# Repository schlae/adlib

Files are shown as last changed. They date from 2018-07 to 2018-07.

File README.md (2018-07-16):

# adlib
Reproduction AdLib Sound Card, OPL2, Circa 1990

For details see http://tubetime.us/?p=419.

This is a (nearly) exact clone of the 1990 version of the AdLib sound card.

User root42 has created a Mouser project with the parts in the BOM at https://www.mouser.com/ProjectManager/ProjectDetail.aspx?AccessID=b0869fd937

This work is licensed under a Creative Commons Attribution 4.0 International License. See https://creativecommons.org/licenses/by/4.0/

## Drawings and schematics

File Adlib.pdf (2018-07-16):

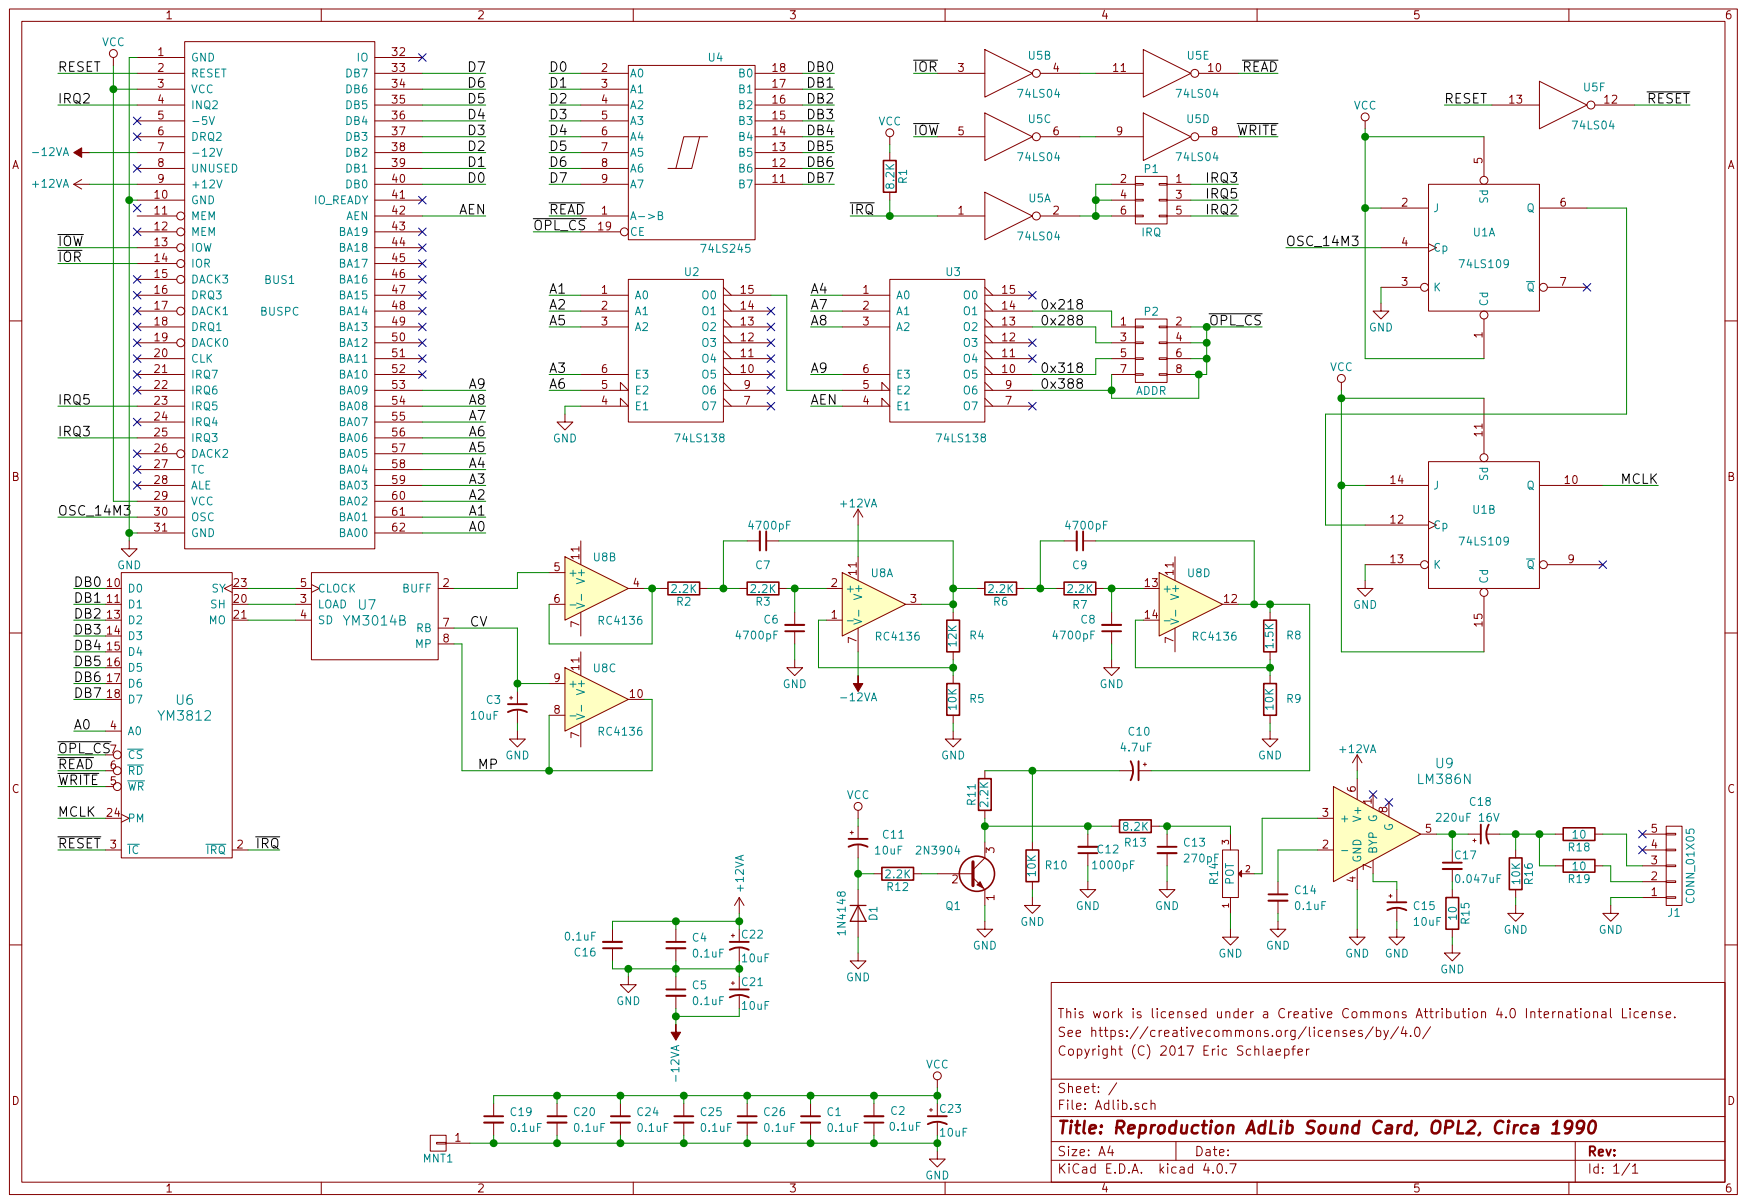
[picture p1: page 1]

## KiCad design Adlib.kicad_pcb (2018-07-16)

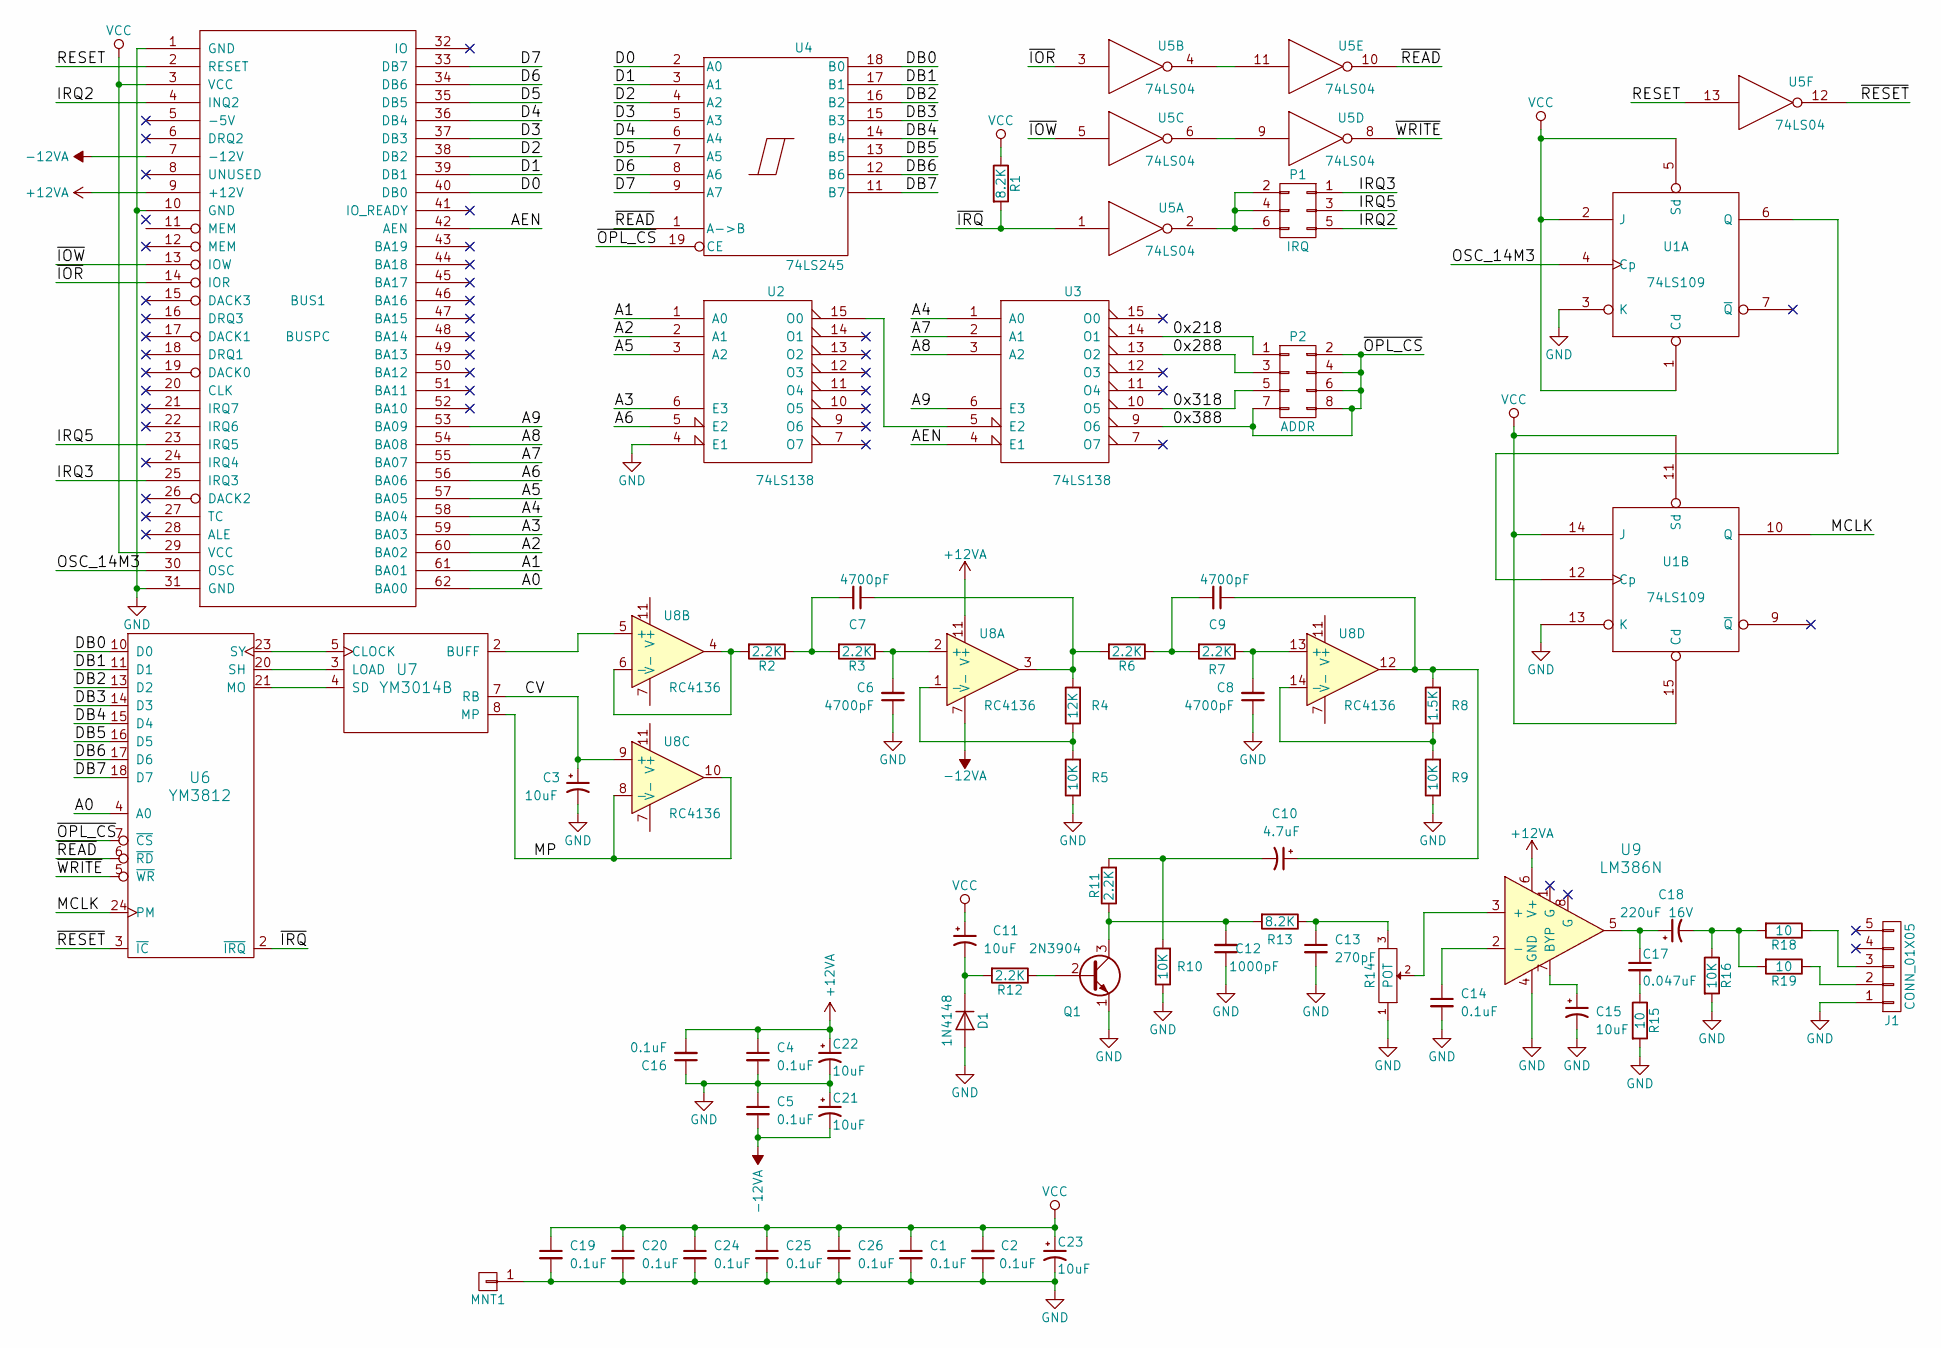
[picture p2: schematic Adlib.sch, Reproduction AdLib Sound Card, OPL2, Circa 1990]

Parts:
BUS1: BUSPC; BUS_PC_ADLIB
C1, C2, C4, C5, C14, C16, C19, C20, C24, C25, C26: 0.1uF; CAP23; Mouser 581-AR215C104K4R
C3, C11, C15, C21, C22, C23: 10uF; CAPAP200; Mouser 581-TAP106M025CRW
C6, C7, C8, C9: 4700pF; CAP23; Mouser 581-AR211C472K4R
C10: 4.7uF; CAPAP200; Mouser 581-TAP475K016SCS
C12: 1000pF; CAP23; Mouser 581-AR211C102K4R
C13: 270pF; CAP23; Mouser 594-S271K43SL0N6TK5R
C17: 0.047uF; CAP23; Mouser 581-AR215C473K4R
C18: 220uF 16V; CAPA1000; Mouser 647-TVX1C221MAD
D1: 1N4148; DIOA500; Mouser 512-1N4148
J1: CONN_01X05; JACK_CUI_SJ1-3553NG; Mouser 490-SJ1-3553NG
MNT1: CONN_01X01; MNT_KEYSTONE_9202; Mouser 534-9202
P1: IRQ; JMP3
P2: ADDR; JMP4
Q1: 2N3904; TO92-IL; Mouser 512-2N3904BU
R1, R13: 8.2K; RESA500; Mouser 291-8.2K-RC
R2, R3, R6, R7, R11, R12: 2.2K; RESA500; Mouser 291-2.2K-RC
R4: 12K; RESA500; Mouser 291-12K-RC
R5, R9, R10, R16: 10K; RESA500; Mouser 291-10K-RC
R8: 1.5K; RESA500; Mouser 291-1.5K-RC
R14: POT; RESV_BOURNS_91A1A; Mouser 652-91A1A-B24-D15L
R15, R18, R19: 10; RESA500; Mouser 291-10-RC
U1: 74LS109; DIP300_16N; Mouser 595-SN74LS109AN
U2, U3: 74LS138; DIP300_16N; Mouser 595-SN74LS138N
U4: 74LS245; DIP300_20N; Mouser 595-SN74LS245N
U5: 74LS04; DIP300_14N; Mouser 595-SN74LS04N
U6: YM3812; DIP600_24N
U7: YM3014B; DIP300_8N
U8: RC4136; DIP300_14N; Mouser 595-RC4136N
U9: LM386N; DIP300_8N; Mouser 926-LM386N-4/NOPB

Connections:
+12VA: BUS1.9 (+12V), C4.1, C16.2, C22.1, U8.11 (V+), U9.6 (V+)
-12VA: BUS1.7 (-12V), C5.2, C21.2, U8.7 (V-)
/0x218: P2.1, U3.14 (O1)
/0x288: P2.3, U3.13 (O2)
/0x318: P2.5, U3.10 (O5)
/0x388: P2.2, P2.4, P2.6, P2.7, P2.8, U3.9 (O6), U4.19 (CE), U6.7 (~CS)
/A0: BUS1.62 (BA00), U6.4 (A0)
/A1: BUS1.61 (BA01), U2.1 (A0)
/A2: BUS1.60 (BA02), U2.2 (A1)
/A3: BUS1.59 (BA03), U2.6 (E3)
/A4: BUS1.58 (BA04), U3.1 (A0)
/A5: BUS1.57 (BA05), U2.3 (A2)
/A6: BUS1.56 (BA06), U2.5 (E2)
/A7: BUS1.55 (BA07), U3.2 (A1)
/A8: BUS1.54 (BA08), U3.3 (A2)
/A9: BUS1.53 (BA09), U3.6 (E3)
/AEN: BUS1.42 (AEN), U3.4 (E1)
/CV: C3.1, U7.7 (RB), U8.9 (+)
/D0: BUS1.40 (DB0), U4.2 (A0)
/D1: BUS1.39 (DB1), U4.3 (A1)
/D2: BUS1.38 (DB2), U4.4 (A2)
/D3: BUS1.37 (DB3), U4.5 (A3)
/D4: BUS1.36 (DB4), U4.6 (A4)
/D5: BUS1.35 (DB5), U4.7 (A5)
/D6: BUS1.34 (DB6), U4.8 (A6)
/D7: BUS1.33 (DB7), U4.9 (A7)
/DB0: U4.18 (B0), U6.10 (D0)
/DB1: U4.17 (B1), U6.11 (D1)
/DB2: U4.16 (B2), U6.13 (D2)
/DB3: U4.15 (B3), U6.14 (D3)
/DB4: U4.14 (B4), U6.15 (D4)
/DB5: U4.13 (B5), U6.16 (D5)
/DB6: U4.12 (B6), U6.17 (D6)
/DB7: U4.11 (B7), U6.18 (D7)
/IRQ2: BUS1.4 (INQ2), P1.5
/IRQ3: BUS1.25 (IRQ3), P1.1
/IRQ5: BUS1.23 (IRQ5), P1.3
/MCLK: U1.10 (Q), U6.24 (PM)
/MP: U7.8 (MP), U8.8 (-), U8.10
/OSC_14M3: BUS1.30 (OSC), U1.4 (Cp)
/RESET: BUS1.2 (RESET), U5.13
/~IOR: BUS1.14 (IOR), U5.3
/~IOW: BUS1.13 (IOW), U5.5
/~IRQ: R1.2, U5.1, U6.2 (~IRQ)
/~READ: U4.1 (A->B), U5.10, U6.6 (~RD)
/~RESET: U5.12, U6.3 (~IC)
/~WRITE: U5.8, U6.5 (~WR)
GND: BUS1.1 (GND), BUS1.10 (GND), BUS1.31 (GND), C1.2, C2.1, C3.2, C4.2, C5.1, C6.1, C8.1, C12.1, C13.2, C14.2, C15.2, C16.1, C19.2, C20.2, C21.1, C22.2, C23.2, C24.2, C25.2, C26.2, D1.2 (A), J1.1, MNT1.1, Q1.1 (E), R5.1, R9.1, R10.1, R14.1, R15.2, R16.2, U1.3 (K), U1.8 (GND), U1.13 (K), U2.4 (E1), U2.8 (GND), U3.8 (GND), U4.10 (GND), U5.7 (GND), U6.12 (GND), U7.6 (GND), U9.4 (GND)
unnamed: C6.2, R3.1, U8.2 (+)
unnamed: C7.1, R4.2, R6.2, U8.3
unnamed: C7.2, R2.1, R3.2
unnamed: C8.2, R7.1, U8.13 (+)
unnamed: C9.2, R6.1, R7.2
unnamed: C9.1, C10.1, R8.2, U8.12
unnamed: C10.2, R10.2, R11.2
unnamed: C11.2, D1.1 (K), R12.2
unnamed: C12.2, Q1.3 (C), R11.1, R13.2
unnamed: C13.1, R13.1, R14.3
unnamed: C14.1, U9.2 (-)
unnamed: C15.1, U9.7 (BYP)
unnamed: C17.1, C18.1, U9.5
unnamed: C17.2, R15.1
unnamed: C18.2, R16.1, R18.2, R19.2
unnamed: J1.2, R19.1
unnamed: J1.3, R18.1
unnamed: P1.2, P1.4, P1.6, U5.2
unnamed: Q1.2 (B), R12.1
unnamed: R2.2, U8.4, U8.6 (-)
unnamed: R4.1, R5.2, U8.1 (-)
unnamed: R8.1, R9.2, U8.14 (-)
unnamed: R14.2, U9.3 (+)
unnamed: U1.6 (Q), U1.12 (Cp)
unnamed: U2.15 (O0), U3.5 (E2)
unnamed: U5.6, U5.9
unnamed: U5.4, U5.11
unnamed: U6.20 (SH), U7.3 (LOAD)
unnamed: U6.21 (MO), U7.4 (SD)
unnamed: U6.23 (SY), U7.5 (CLOCK)
unnamed: U7.2 (BUFF), U8.5 (+)
VCC: BUS1.3 (VCC), BUS1.29 (VCC), C1.1, C2.2, C11.1, C19.1, C20.1, C23.1, C24.1, C25.1, C26.1, R1.1, U1.1 (Cd), U1.2 (J), U1.5 (Sd), U1.11 (Sd), U1.14 (J), U1.15 (Cd), U1.16 (VCC), U2.16 (VCC), U3.16 (VCC), U4.20 (VCC), U5.14 (VCC), U6.1 (VCC), U7.1 (VCC)

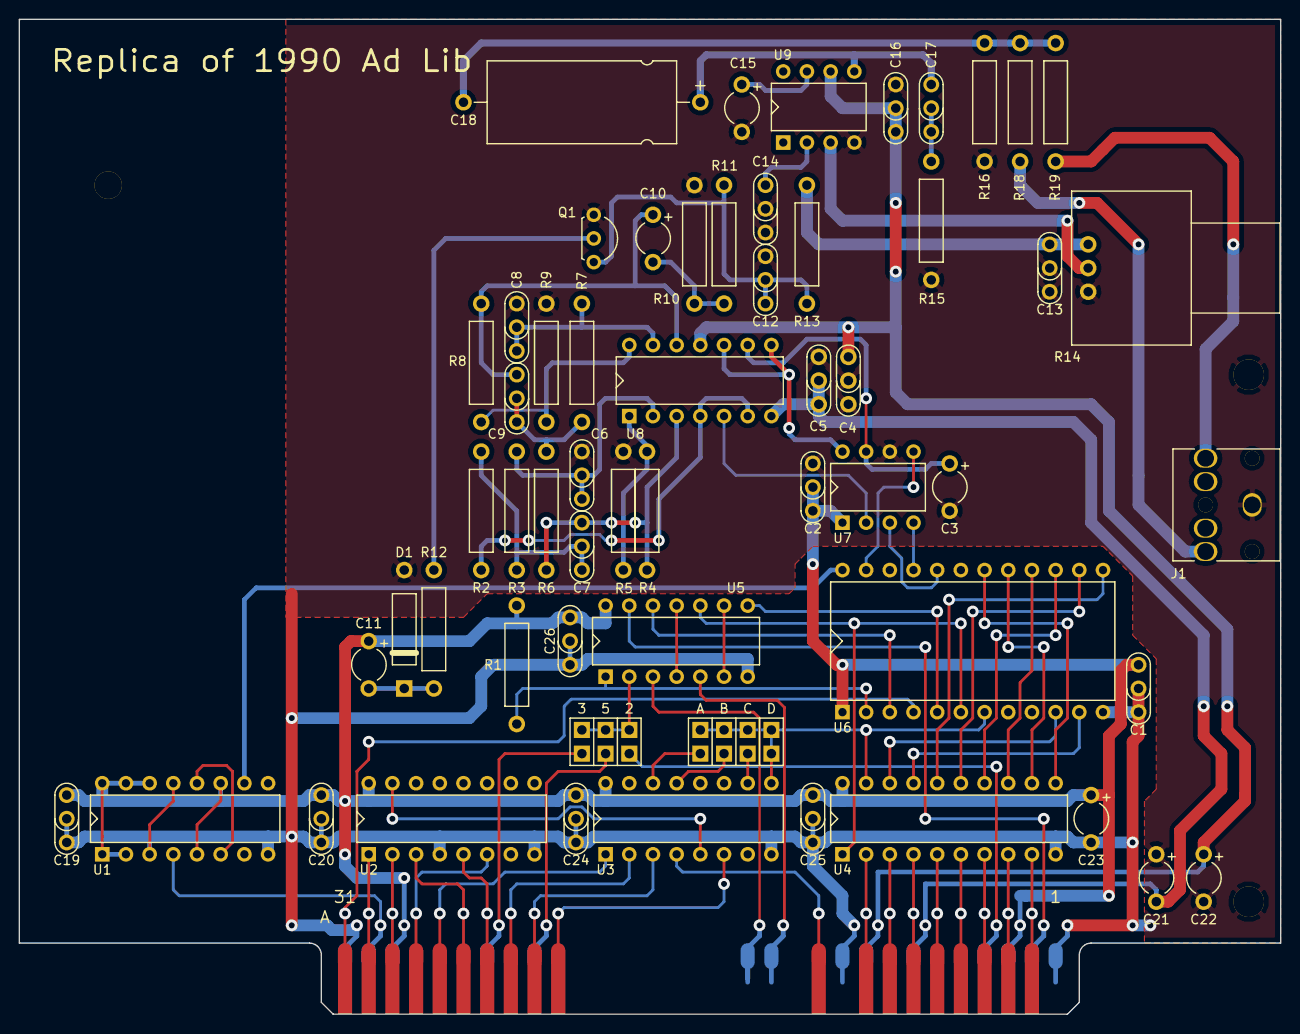
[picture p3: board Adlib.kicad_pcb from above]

Board: 2 copper layers, 135.3 x 106.7 mm, 60 parts (0 on the bottom side), 80 nets.

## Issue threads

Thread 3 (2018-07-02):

PDF schematics and PCBs

tonyp7, 2018-07-02:
Hello,

Most electronics projects provide a PDF schematics and PCB for people and I've always found them a lot more useful than the source files. Could you provide that? I am not a kicad user and probbaly  a lot of us arn't! Thanks for this cool project btw!

Tony

schlae, 2018-07-02:
PDF schematics now up!

Closed 2018-07-02.

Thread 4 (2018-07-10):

license

TGC-TECH, 2018-07-10:
What license is the PCB design under, if I wanted to produce a few of these and then resell them for profit as reproduction cards is that allowed? Who should I credit as creating the actual PCB design? etc...

TGC-TECH, 2018-07-10:
I am an idiot, because you didn't use the GitHub license feature I looked past it in the read me. Sorry

Closed 2018-07-10.

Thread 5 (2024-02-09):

3D printed bracket (with or without screws for locking the bracket to the card)

giobbino, 2024-02-09:
Hello,

I released a couple of STL files on Thingiverse that fit perfectly the board:

https://www.thingiverse.com/thing:6476527

One requires two screws to lock it on the board, the other one simply has two pins that fit the the screw holes and can be melted with an iron solder to firmly lock the board (of course using two screws is the best option)

Just in case anybody should need. Hope it helps!

Cheers,
Giovi

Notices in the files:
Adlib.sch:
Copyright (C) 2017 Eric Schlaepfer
